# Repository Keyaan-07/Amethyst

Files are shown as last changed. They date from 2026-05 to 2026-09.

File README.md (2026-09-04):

# Amethyst
Amethyst is an 84-key keyboard with a small form factor. It comes with the RP2040 and i have used purple akko v3 switches to give it purple colour. This keyboard runs qmk firmware and can be found under firmware. The complete design file is amethyst.step.

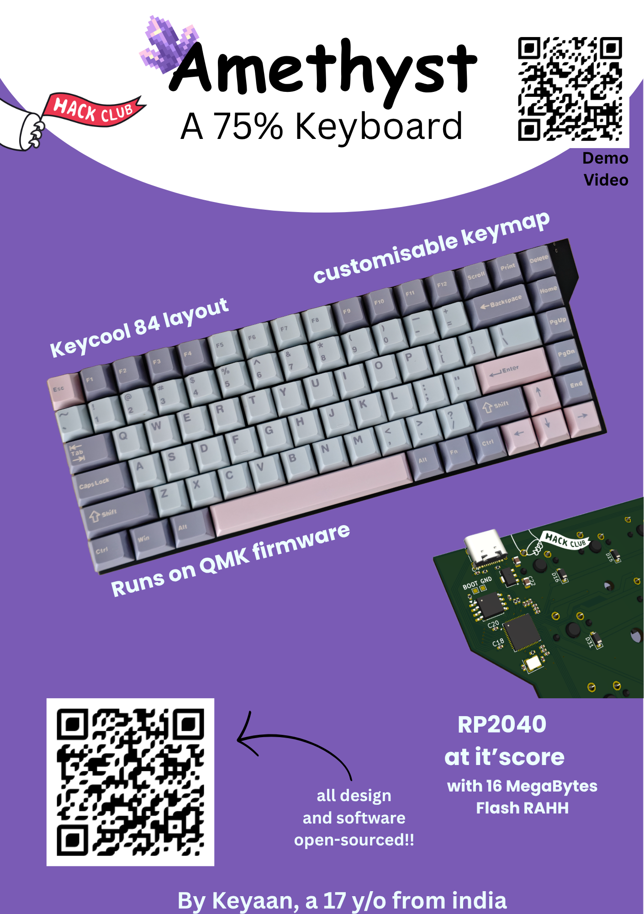
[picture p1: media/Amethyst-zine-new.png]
zine page

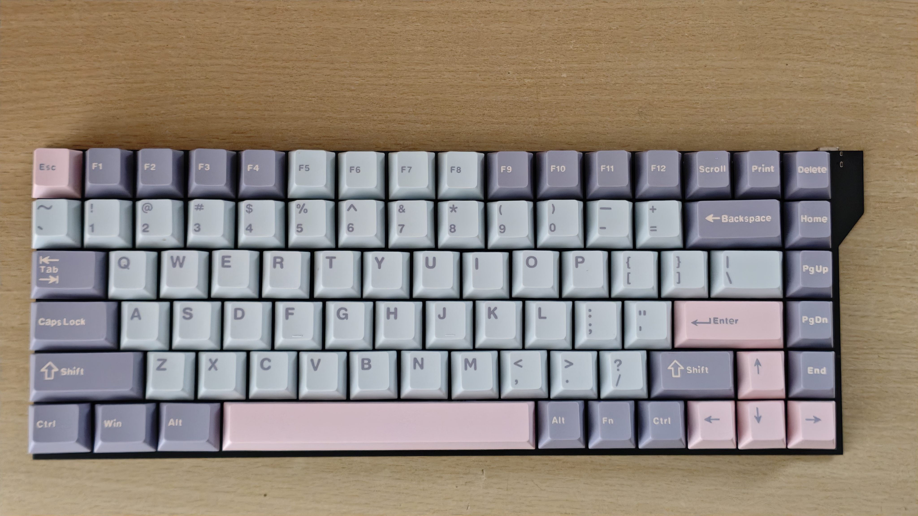
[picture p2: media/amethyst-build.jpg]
build

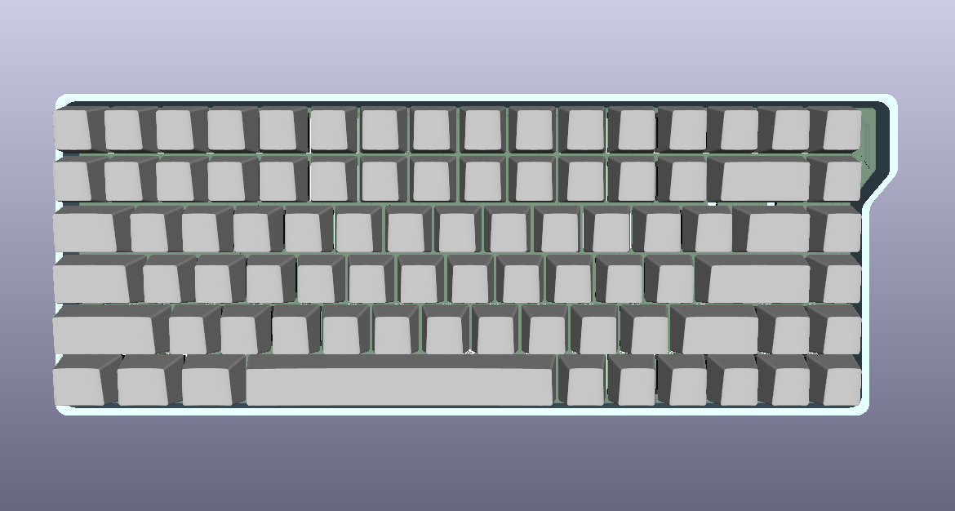
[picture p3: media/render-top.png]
render-top

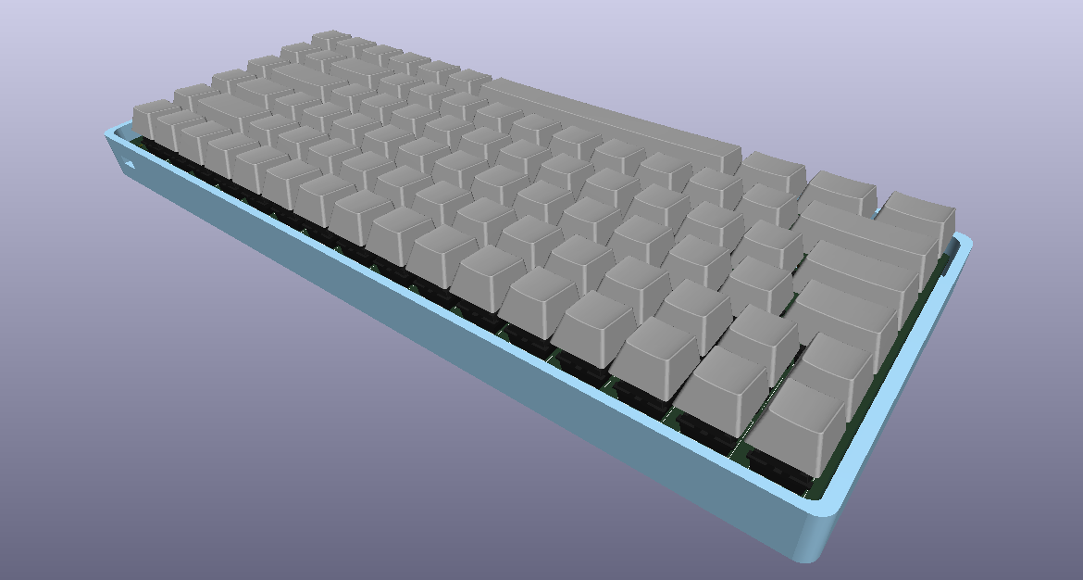
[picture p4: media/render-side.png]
render-side

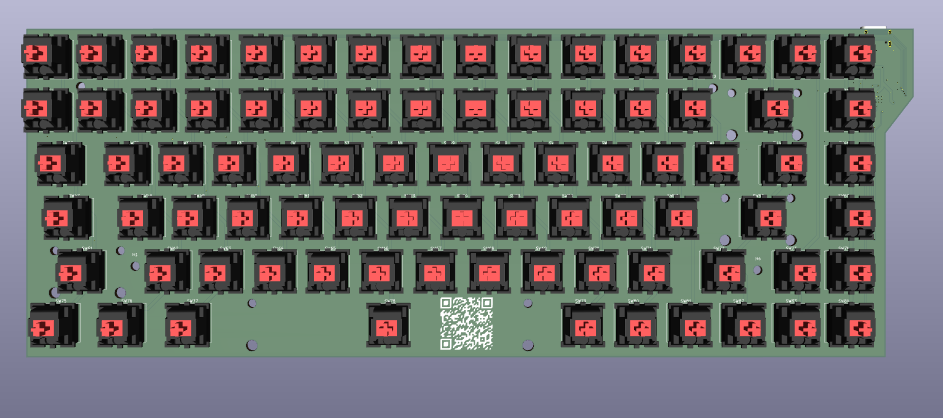
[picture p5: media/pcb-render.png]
pcb-render

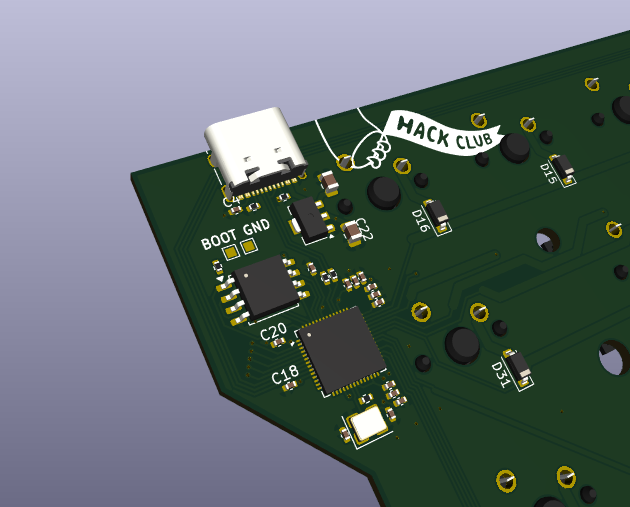
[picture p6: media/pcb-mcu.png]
pcb-mcu

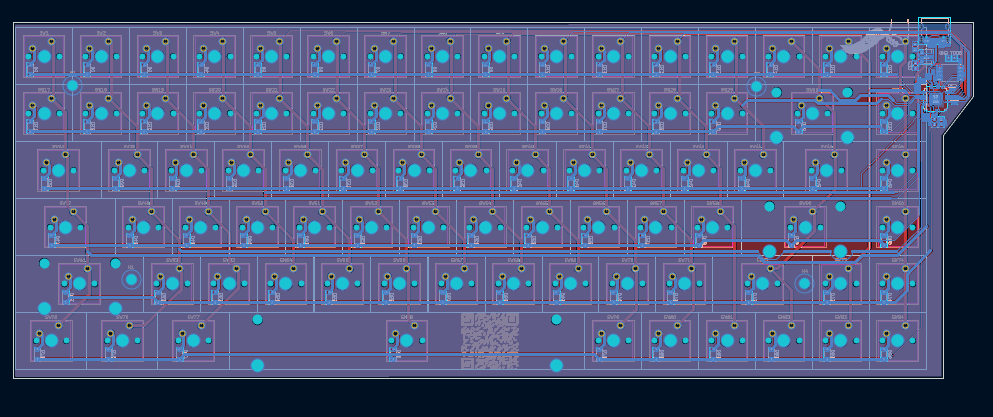
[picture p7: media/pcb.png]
pcb

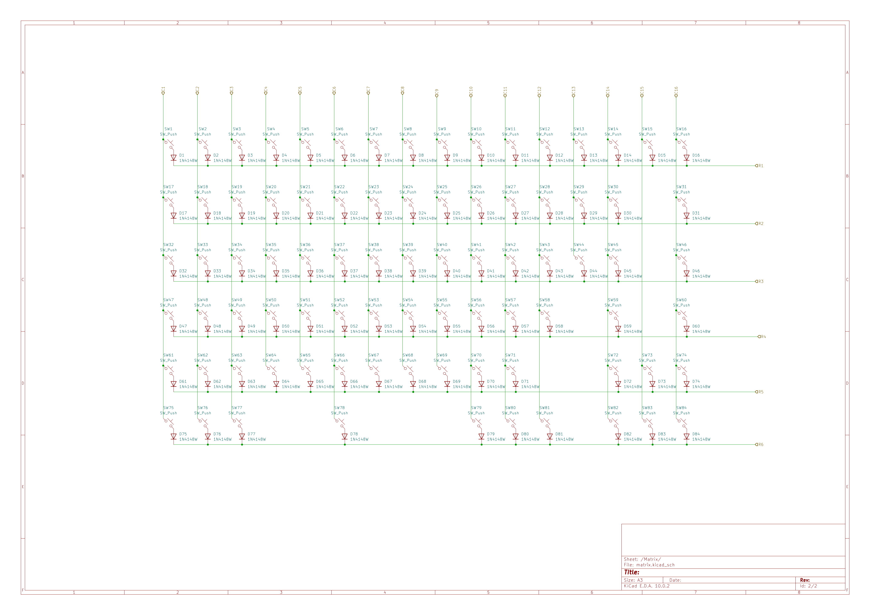
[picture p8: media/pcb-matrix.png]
matrix


# Soldering and setup
1. Order the PCB from the gerbers present in hardware/production. 
2. order the parts from the given links in bom.csv file
3. first solder the smd components on the back side and then proceed to the through hole keys. 
4. press the heated inserts in the case with the help of a soldering iron. 
5. screw in the case. 
6. fit the keycaps on the top. 
7. short the BOOT and GND pads with a screwdriver and plug in the usb cable.
8. go to the firmware folder and download the .uf2 file. 
9. drag and drop the .uf2 file to the "RPI-RP2" drive that just popped up.
10. Your keyboard is now ready!!

## Why I made this keyboard
 I am getting a new laptop this year and did not want to let go of the keymap of the old keyboard, thus I created amethyst. 

# BOM
|Designator |Function |Value |Footprint |Quantity|Price |Amount |Order|Link |
|---|---|---|---|---|---|---|-----|---|
|PCB |Main PCB | |119x312 |5 |8.934 |44.67  |Yes  |https://robu.in/product/online-pcb-manufacturing-service/ |
|Keycaps |Purple keycaps | | |1 |11.48 |11.48  |Yes  |https://curiositycaps.in/products/macarons-cherry-pbt-keycaps?_pos=368&_fid=c796727f4&_ss=c |
|Keys |Akko v3 lavender(pack of 45)  | | |2 |11.48 |22.96  |Yes  |https://stackskb.com/store/akko-v3-lavender-purple-pro-switch-pack-of-45/ |
|Stabilizers |Clear | | |1 |11.67 |11.67  |Yes  |https://stackskb.com/store/durock-clear-screw-in-stabilizers-v2/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 |
|Case |print legion | | |1 |0 |0 |Yes  |https://printlegion.hackclub.com/ |
|C1, C2 |Capacitor |15p |402 |2 |0.017 |0.034  |Yes  |https://robu.in/product/gjm1555c1h150gb01d-murata-electronics-50v-15pf-null-%c2%b12-0402-multilayer-ceramic-capacitors-mlcc-smd-smt-rohs/|
|C13, C22 |Capacitor |10u |805 |2 |0.05 |0.1 |No |https://www.lcsc.com/product-detail/C2932476.html |
|C14, C15, C16, C17, C18, C19, C20, C23, C24, C25 |Capacitor |100n |402 |10 |0.0074  |0.074  |No |https://www.lcsc.com/product-detail/C426067.html |
|C4, C5, C6 |Capacitor |1u |402 |3 |0.02 |0.06 |No |https://www.lcsc.com/product-detail/C1518208.html |
|D1, D10, D11, D12, D13, D14, D15, D16, D17, D18, D19, D2, D20, D21, D22, D23, D24, D25, D26, D27, D28, D29, D3, D30, D31, D32, D33, D34, D35, D36, D37, D38, D39, D4, D40, D41, D42, D43, D44, D45, D46, D47, D48, D49, D5, D50, D51, D52, D53, D54, D55, D56, D57, D58, D59, D6, D60, D61, D62, D63, D64, D65, D66, D67, D68, D69, D7, D70, D71, D72, D73, D74, D75, D76, D77, D78, D79, D8, D80, D81, D82, D83, D84, D9|Diodes |1N4148W |D_SOD-123 |90 |0.0073  |0.657  |Yes  |https://robu.in/product/1n4148w-sod-123-1206-diodereel-of-3000/ |
|J2 |USB-C |USB_C_Receptacle_USB2.0_16P|USB_C_Receptacle_XKB_U262-16XN-4BVC11|1 |0.06 |0.06 |No |https://www.lcsc.com/product-detail/C393939.html |
|R1, R2 |Resistors |5.1k |402 |2 |0.005 |0.01 |No |https://www.lcsc.com/product-detail/C278598.html |
|R3, R6 |Resistors |1k |402 |2 |0.02 |0.04 |No |https://www.lcsc.com/product-detail/C427241.html |
|R4, R5 |Resistors |27 |402 |2 |0.0039  |0.0078 |No |https://www.lcsc.com/product-detail/C278580.html |
|U1 |MCU |RP2040 |QFN-56-1EP_7x7mm_P0.4mm_EP3.2x3.2mm  |2 |0.89 |1.78 |Yes  |https://robu.in/product/raspberry-pi-rp2040/ |
|U2 |Flash |W25Q128JVS |SOIC-8_5.3x5.3mm_P1.27mm |1 |1.1 |1.1 |No |https://www.lcsc.com/product-detail/C2613930.html |
|U3 |Regulator |AMS1117-3.3 |SOT-89-3 |1 |0.1 |0.1 |No |https://www.lcsc.com/product-detail/C917152.html |
|Y1 |Crystal Oscillator |Crystal_GND24 |Crystal_SMD_3225-4Pin_3.2x2.5mm |1 |0.38 |0.38 |No |https://www.lcsc.com/product-detail/C20625731.html |
| | | | | |Shipping|0.51 | | |
| | | | | |Total |100.693| | |

# 3d Files link
All the 3d files can be found on onshape [here](https://cad.onshape.com/documents/0f11901139fd6ce9006e5c5f/w/93aac7747a7c2381c6948375/e/141b0f824d8e79d984ecb6aa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)

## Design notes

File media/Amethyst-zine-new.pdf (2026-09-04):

## A 75% Keyboard

# Amethyst

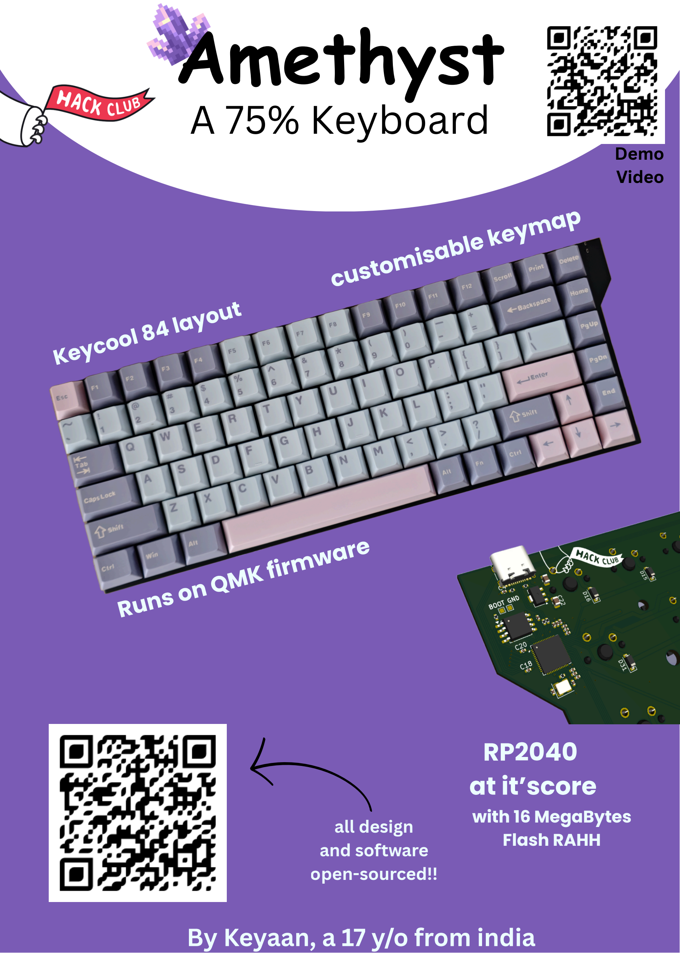
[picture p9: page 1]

By Keyaan, a 17 y/o from india all design
and software
open-sourced!!

Runs on QMK firmware

customisable keymap

RP2040
at it’score
with 16 MegaBytes
Flash RAHH

Keycool 84 layout

Demo
Video

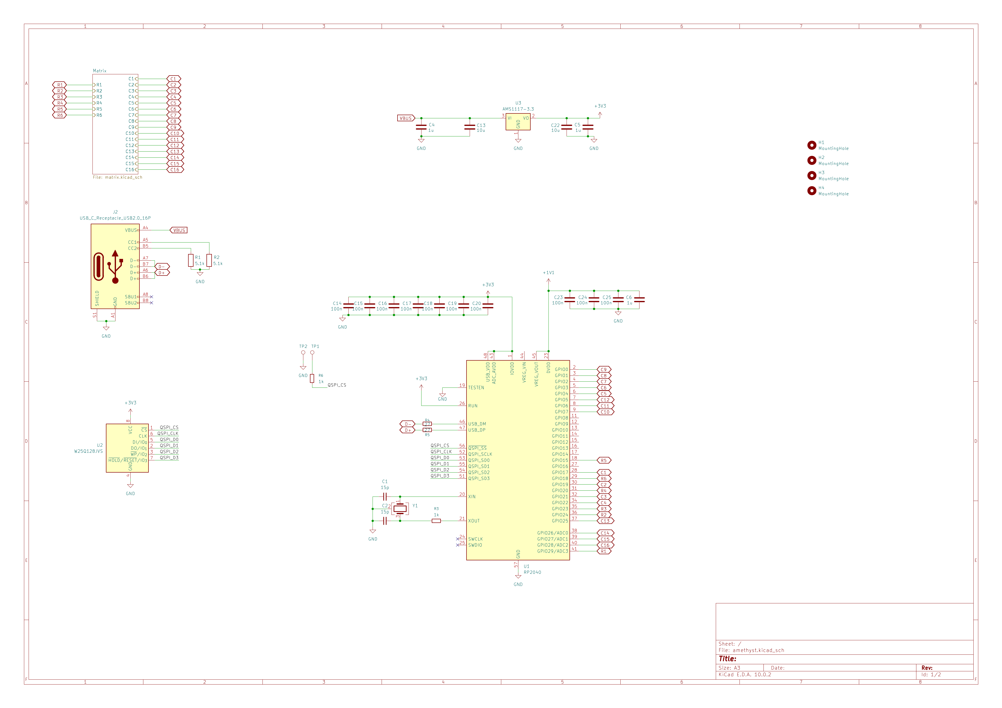
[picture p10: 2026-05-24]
media/schematic-mcu.png

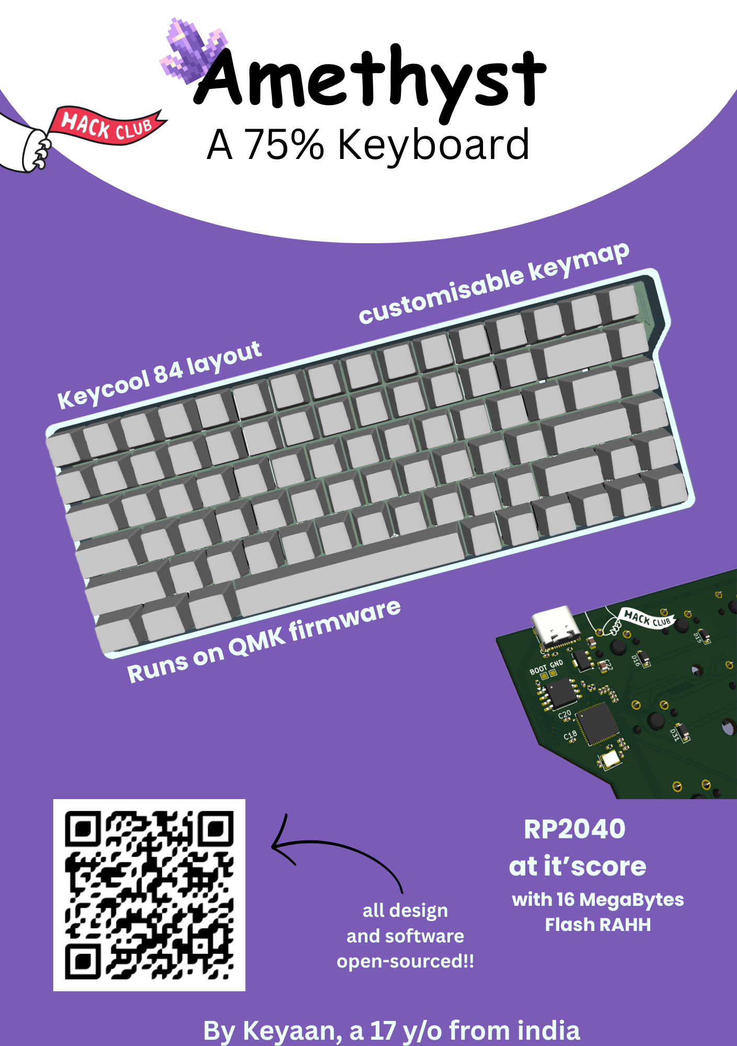
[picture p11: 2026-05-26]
media/Amethyst-zine.png

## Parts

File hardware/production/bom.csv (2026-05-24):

Designator | Footprint | Quantity | Value | LCSC Part #
C1, C2 | 0402 | 2 | 15p
C13, C22 | 0805 | 2 | 10u
C14, C15, C16, C17, C18, C19, C20, C23, C24, C25 | 0402 | 10 | 100n
C4, C5, C6 | 0402 | 3 | 1u
D1, D10, D11, D12, D13, D14, D15, D16, D17, D18, D19, D2, D20, D21, D22, D23, D24, D25, D26, D27, D28, D29, D3, D30, D31, D32, D33, D34, D35, D36, D37, D38, D39, D4, D40, D41, D42, D43, D44, D45, D46, D47, D48, D49, D5, D50, D51, D52, D53, D54, D55, D56, D57, D58, D59, D6, D60, D61, D62, D63, D64, D65, D66, D67, D68, D69, D7, D70, D71, D72, D73, D74, D75, D76, D77, D78, D79, D8, D80, D81, D82, D83, D84, D9 | D_SOD-123 | 84 | 1N4148W
J2 | USB_C_Receptacle_XKB_U262-16XN-4BVC11 | 1 | USB_C_Receptacle_USB2.0_16P
R1, R2 | 0402 | 2 | 5.1k
R3, R6 | 0402 | 2 | 1k
R4, R5 | 0402 | 2 | 27
SW1, SW10, SW11, SW12, SW13, SW14, SW15, SW16, SW17, SW18, SW19, SW2, SW20, SW21, SW22, SW23, SW24, SW25, SW26, SW27, SW28, SW29, SW3, SW31, SW33, SW34, SW35, SW36, SW37, SW38, SW39, SW4, SW40, SW41, SW42, SW43, SW44, SW46, SW48, SW49, SW5, SW50, SW51, SW52, SW53, SW54, SW55, SW56, SW57, SW58, SW6, SW60, SW62, SW63, SW64, SW65, SW66, SW67, SW68, SW69, SW7, SW70, SW71, SW73, SW74, SW79, SW8, SW80, SW81, SW82, SW83, SW84, SW9 | SW_Cherry_MX_1.00u_PCB | 73 | SW_Push
SW30 | SW_Cherry_MX_2.00u_PCB | 1 | SW_Push
SW32, SW45 | SW_Cherry_MX_1.50u_PCB | 2 | SW_Push
SW47, SW72 | SW_Cherry_MX_1.75u_PCB | 2 | SW_Push
SW59, SW61 | SW_Cherry_MX_2.25u_PCB | 2 | SW_Push
SW75, SW76, SW77 | SW_Cherry_MX_1.25u_PCB | 3 | SW_Push
SW78 | SW_Cherry_MX_6.25u_PCB | 1 | SW_Push
TP1, TP2 | TestPoint_Pad_1.0x1.0mm | 2 | TestPoint
U1 | QFN-56-1EP_7x7mm_P0.4mm_EP3.2x3.2mm | 1 | RP2040
U2 | SOIC-8_5.3x5.3mm_P1.27mm | 1 | W25Q128JVS
U3 | SOT-89-3 | 1 | AMS1117-3.3
Y1 | Crystal_SMD_3225-4Pin_3.2x2.5mm | 1 | Crystal_GND24

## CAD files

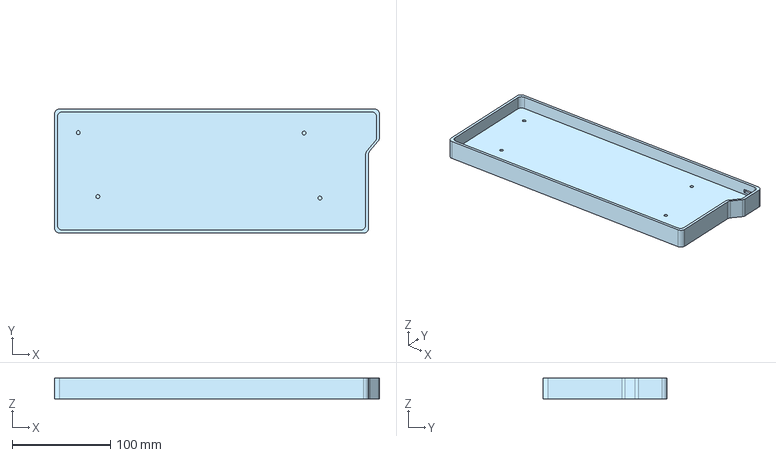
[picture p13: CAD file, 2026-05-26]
threedimensions/Amethyst_case.step
330.0 x 126.0 x 21.0 mm

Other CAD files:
threedimensions/amethyst_case.stl

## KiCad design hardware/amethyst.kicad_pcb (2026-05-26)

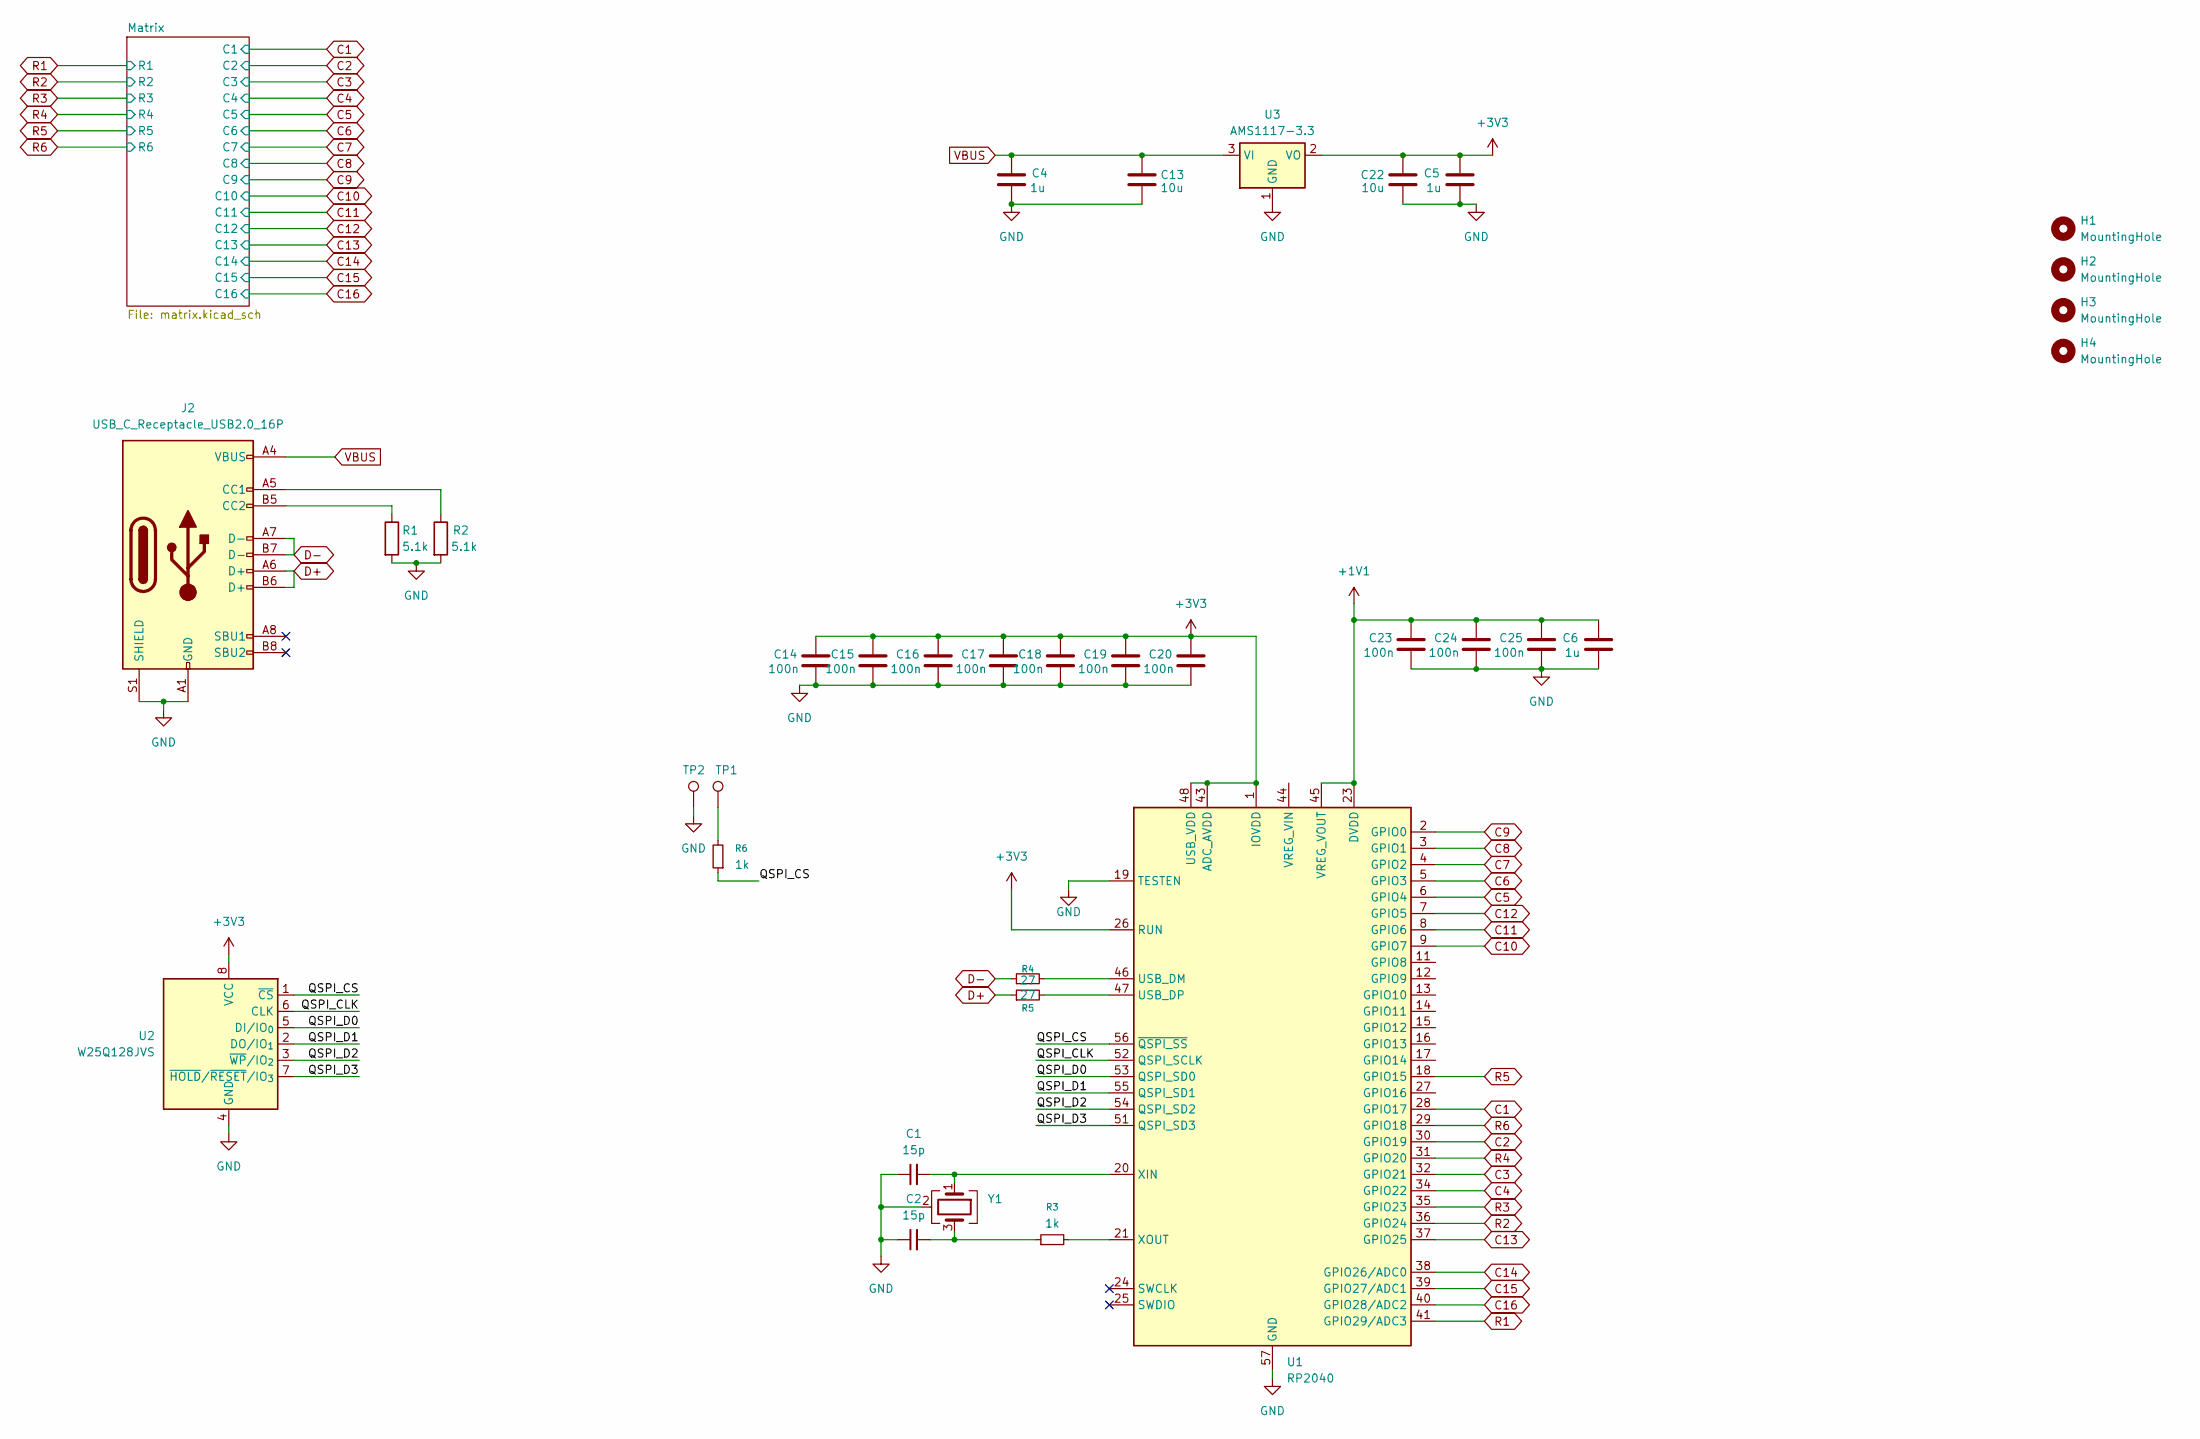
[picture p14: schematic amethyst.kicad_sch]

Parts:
C1, C2: 15p; C_0402_1005Metric
C4, C5, C6: 1u; C_0402_1005Metric
C13, C22: 10u; C_0805_2012Metric
C14, C15, C16, C17, C18, C19, C20, C23, C24, C25: 100n; C_0402_1005Metric
H1, H2, H3, H4: MountingHole; MountingHole_3.2mm_M3
J2: USB_C_Receptacle_USB2.0_16P; USB_C_Receptacle_XKB_U262-16XN-4BVC11
R1, R2: 5.1k; R_0402_1005Metric
R3, R6: 1k; R_0402_1005Metric
R4, R5: 27; R_0402_1005Metric
TP1, TP2: TestPoint; TestPoint_Pad_1.0x1.0mm
U1: RP2040; QFN-56-1EP_7x7mm_P0.4mm_EP3.2x3.2mm
U2: W25Q128JVS; SOIC-8_5.3x5.3mm_P1.27mm
U3: AMS1117-3.3; SOT-89-3
Y1: Crystal_GND24; Crystal_SMD_3225-4Pin_3.2x2.5mm

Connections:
+1V1: C6.2, C23.2, C24.2, C25.2, U1.23 (DVDD), U1.45 (VREG_VOUT), U1.50 (DVDD)
+3V3: C5.2, C14.2, C15.2, C16.2, C17.2, C18.2, C19.2, C20.2, C22.1, U1.1 (IOVDD), U1.10 (IOVDD), U1.22 (IOVDD), U1.26 (RUN), U1.33 (IOVDD), U1.42 (IOVDD), U1.43 (ADC_AVDD), U1.48 (USB_VDD), U1.49 (IOVDD), U2.8 (VCC), U3.2 (VO)
/QSPI_CLK: U1.52 (QSPI_SCLK), U2.6 (CLK)
/QSPI_CS: R6.1, U1.56 (~QSPI_SS), U2.1 (~CS)
/QSPI_D0: U1.53 (QSPI_SD0), U2.5 (DI/IO_{0})
/QSPI_D1: U1.55 (QSPI_SD1), U2.2 (DO/IO_{1})
/QSPI_D2: U1.54 (QSPI_SD2), U2.3 (~WP/IO_{2})
/QSPI_D3: U1.51 (QSPI_SD3), U2.7 (~HOLD/~RESET/IO_{3})
C1: U1.28 (GPIO17); also elsewhere on the board
C2: U1.30 (GPIO19); also elsewhere on the board
C3: U1.32 (GPIO21); also elsewhere on the board
C4: U1.34 (GPIO22); also elsewhere on the board
C5: U1.6 (GPIO4); also elsewhere on the board
C6: U1.5 (GPIO3); also elsewhere on the board
C7: U1.4 (GPIO2); also elsewhere on the board
C8: U1.3 (GPIO1); also elsewhere on the board
C9: U1.2 (GPIO0); also elsewhere on the board
C10: U1.9 (GPIO7); also elsewhere on the board
C11: U1.8 (GPIO6); also elsewhere on the board
C12: U1.7 (GPIO5); also elsewhere on the board
C13: U1.37 (GPIO25); also elsewhere on the board
C14: U1.38 (GPIO26/ADC0); also elsewhere on the board
C15: U1.39 (GPIO27/ADC1); also elsewhere on the board
C16: U1.40 (GPIO28/ADC2); also elsewhere on the board
D+: J2.A6 (D+), J2.B6 (D+), R5.1
D-: J2.A7 (D-), J2.B7 (D-), R4.1
GND: C1.1, C2.1, C4.1, C5.1, C6.1, C13.2, C14.1, C15.1, C16.1, C17.1, C18.1, C19.1, C20.1, C22.2, C23.1, C24.1, C25.1, J2.A1 (GND), J2.A12 (GND), J2.B1 (GND), J2.B12 (GND), J2.S1 (SHIELD), R1.2, R2.2, TP2.1 (1_1), U1.19 (TESTEN), U1.57 (GND), U2.4 (GND), U3.1 (GND), Y1.2 (G), Y1.4 (G)
unnamed: C2.2, R3.1, Y1.3
unnamed: J2.A5 (CC1), R2.1
unnamed: J2.B5 (CC2), R1.1
unnamed: R6.2, TP1.1 (1_1)
unnamed: R4.2, U1.46 (USB_DM)
unnamed: R5.2, U1.47 (USB_DP)
unnamed: C1.2, U1.20 (XIN), Y1.1
unnamed: R3.2, U1.21 (XOUT)
R1: U1.41 (GPIO29/ADC3); also elsewhere on the board
R2: U1.36 (GPIO24); also elsewhere on the board
R3: U1.35 (GPIO23); also elsewhere on the board
R4: U1.31 (GPIO20); also elsewhere on the board
R5: U1.18 (GPIO15); also elsewhere on the board
R6: U1.29 (GPIO18); also elsewhere on the board
VBUS: C4.2, C13.1, J2.A4 (VBUS), J2.A9 (VBUS), J2.B4 (VBUS), J2.B9 (VBUS), U3.3 (VI)

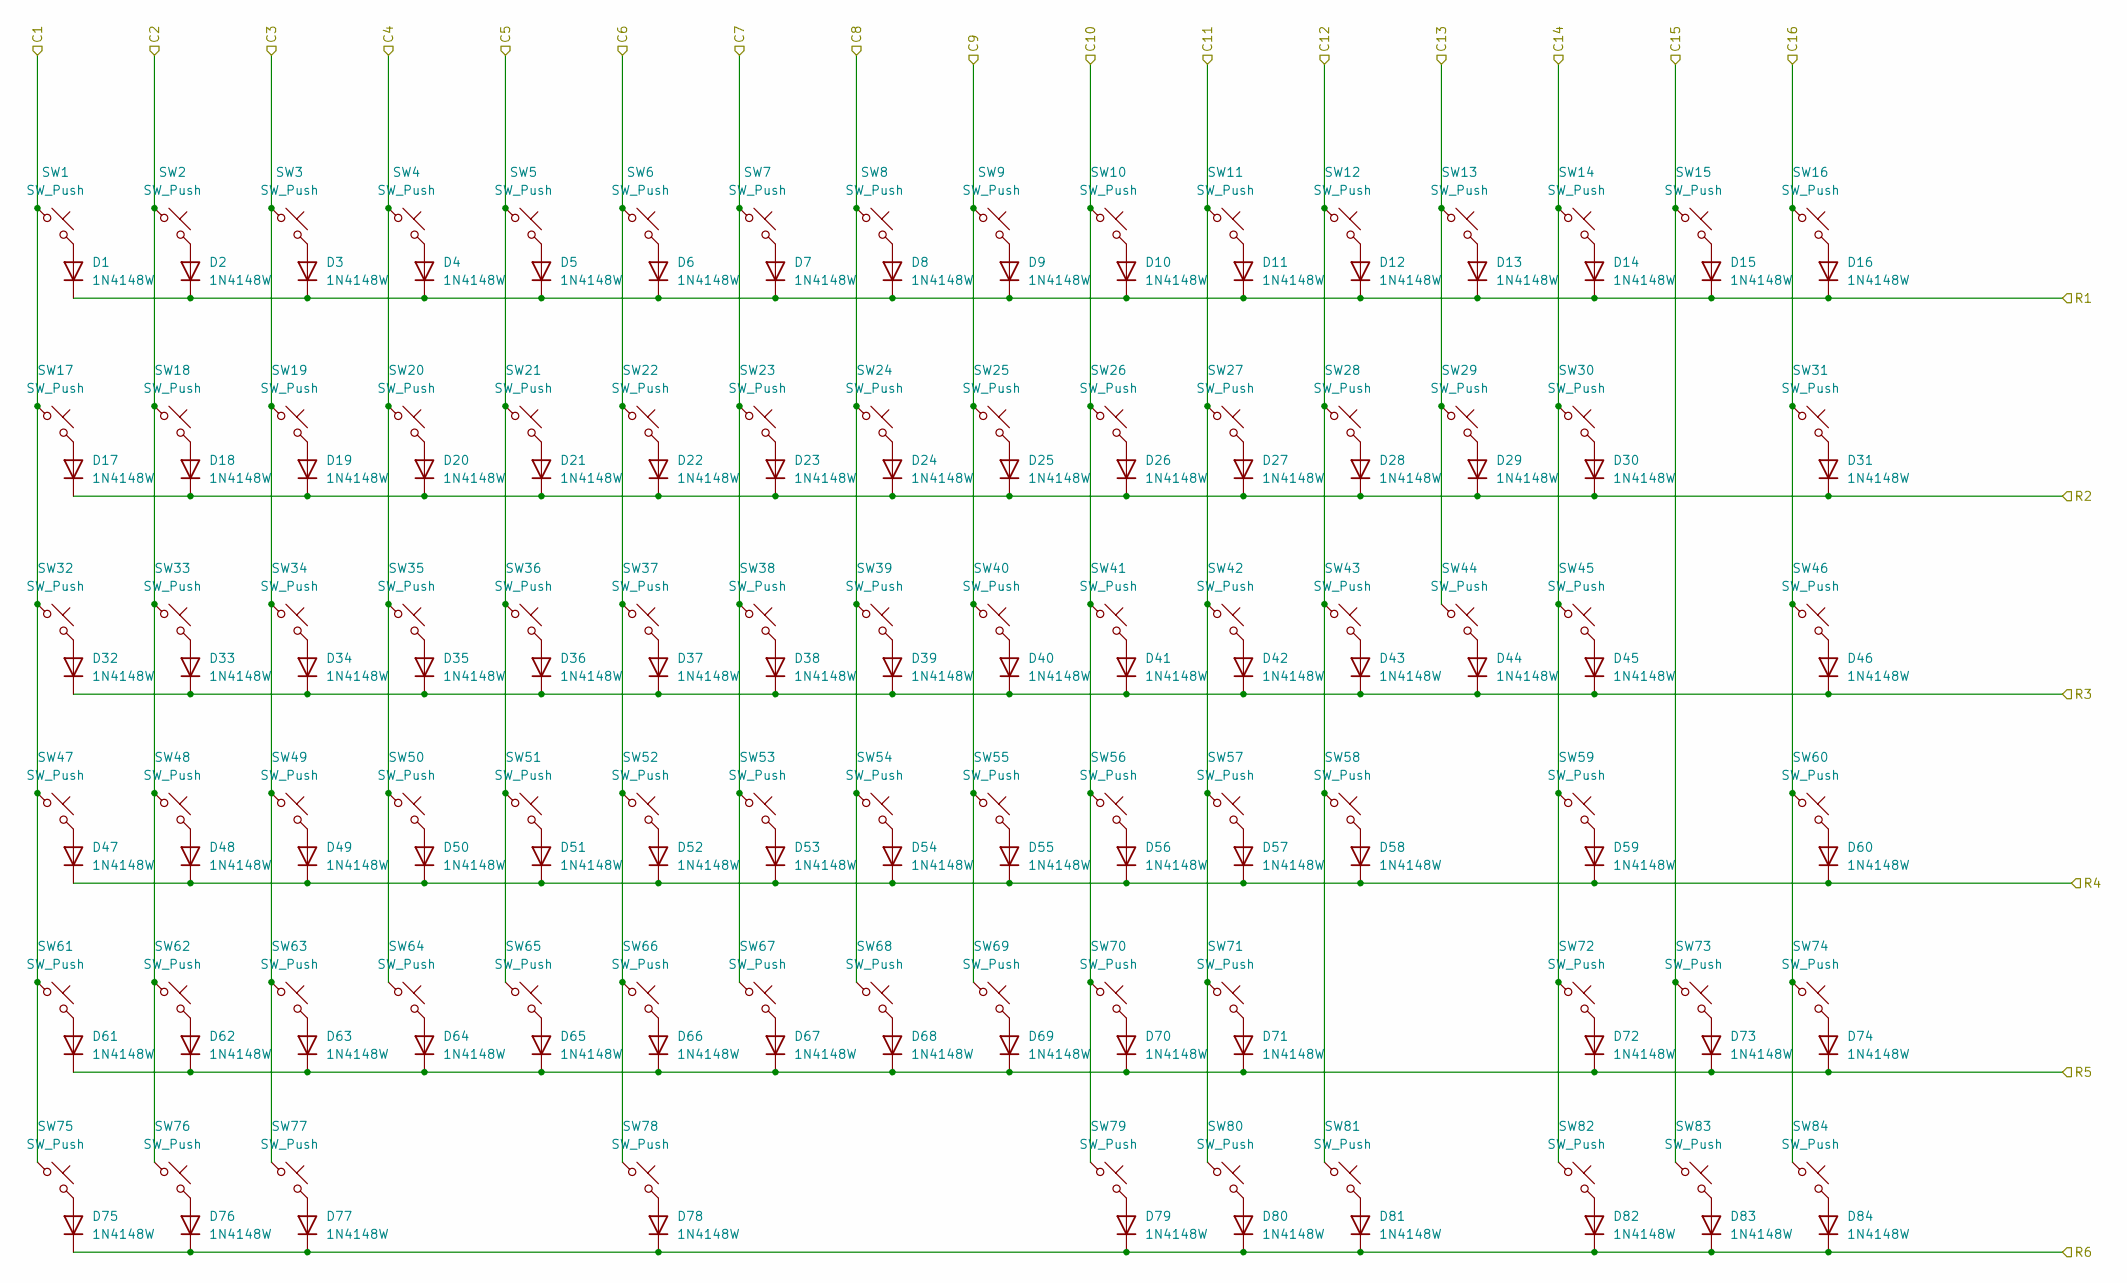
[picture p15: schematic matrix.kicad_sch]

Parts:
D1, D2, D3, D4, D5, D6, D7, D8, D9, D10, D11, D12, D13, D14, D15, D16, D17, D18, D19, D20, D21, D22, D23, D24, D25, D26, D27, D28, D29, D30, D31, D32, D33, D34, D35, D36, D37, D38, D39, D40, D41, D42, D43, D44, D45, D46, D47, D48, D49, D50, D51, D52, D53, D54, D55, D56, D57, D58, D59, D60, D61, D62, D63, D64, D65, D66, D67, D68, D69, D70, D71, D72, D73, D74, D75, D76, D77, D78, D79, D80, D81, D82, D83, D84: 1N4148W; D_SOD-123
SW1, SW2, SW3, SW4, SW5, SW6, SW7, SW8, SW9, SW10, SW11, SW12, SW13, SW14, SW15, SW16, SW17, SW18, SW19, SW20, SW21, SW22, SW23, SW24, SW25, SW26, SW27, SW28, SW29, SW31, SW33, SW34, SW35, SW36, SW37, SW38, SW39, SW40, SW41, SW42, SW43, SW44, SW46, SW48, SW49, SW50, SW51, SW52, SW53, SW54, SW55, SW56, SW57, SW58, SW60, SW62, SW63, SW64, SW65, SW66, SW67, SW68, SW69, SW70, SW71, SW73, SW74, SW79, SW80, SW81, SW82, SW83, SW84: SW_Push; SW_Cherry_MX_1.00u_PCB
SW30: SW_Push; SW_Cherry_MX_2.00u_PCB
SW32, SW45: SW_Push; SW_Cherry_MX_1.50u_PCB
SW47, SW72: SW_Push; SW_Cherry_MX_1.75u_PCB
SW59, SW61: SW_Push; SW_Cherry_MX_2.25u_PCB
SW75, SW76, SW77: SW_Push; SW_Cherry_MX_1.25u_PCB
SW78: SW_Push; SW_Cherry_MX_6.25u_PCB

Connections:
C1: SW1.1, SW17.1, SW32.1, SW47.1, SW61.1, SW75.1; also elsewhere on the board
C2: SW2.1, SW18.1, SW33.1, SW48.1, SW62.1, SW76.1; also elsewhere on the board
C3: SW3.1, SW19.1, SW34.1, SW49.1, SW63.1, SW77.1; also elsewhere on the board
C4: SW4.1, SW20.1, SW35.1, SW50.1, SW64.1; also elsewhere on the board
C5: SW5.1, SW21.1, SW36.1, SW51.1, SW65.1; also elsewhere on the board
C6: SW6.1, SW22.1, SW37.1, SW52.1, SW66.1, SW78.1; also elsewhere on the board
C7: SW7.1, SW23.1, SW38.1, SW53.1, SW67.1; also elsewhere on the board
C8: SW8.1, SW24.1, SW39.1, SW54.1, SW68.1; also elsewhere on the board
C9: SW9.1, SW25.1, SW40.1, SW55.1, SW69.1; also elsewhere on the board
C10: SW10.1, SW26.1, SW41.1, SW56.1, SW70.1, SW79.1; also elsewhere on the board
C11: SW11.1, SW27.1, SW42.1, SW57.1, SW71.1, SW80.1; also elsewhere on the board
C12: SW12.1, SW28.1, SW43.1, SW58.1, SW81.1; also elsewhere on the board
C13: SW13.1, SW29.1, SW44.1; also elsewhere on the board
C14: SW14.1, SW30.1, SW45.1, SW59.1, SW72.1, SW82.1; also elsewhere on the board
C15: SW15.1, SW73.1, SW83.1; also elsewhere on the board
C16: SW16.1, SW31.1, SW46.1, SW60.1, SW74.1, SW84.1; also elsewhere on the board
unnamed: D1.2 (A), SW1.2
unnamed: D2.2 (A), SW2.2
unnamed: D3.2 (A), SW3.2
unnamed: D4.2 (A), SW4.2
unnamed: D5.2 (A), SW5.2
unnamed: D6.2 (A), SW6.2
unnamed: D7.2 (A), SW7.2
unnamed: D8.2 (A), SW8.2
unnamed: D9.2 (A), SW9.2
unnamed: D10.2 (A), SW10.2
unnamed: D11.2 (A), SW11.2
unnamed: D12.2 (A), SW12.2
unnamed: D13.2 (A), SW13.2
unnamed: D14.2 (A), SW14.2
unnamed: D15.2 (A), SW15.2
unnamed: D16.2 (A), SW16.2
unnamed: D17.2 (A), SW17.2
unnamed: D18.2 (A), SW18.2
unnamed: D19.2 (A), SW19.2
unnamed: D20.2 (A), SW20.2
unnamed: D21.2 (A), SW21.2
unnamed: D22.2 (A), SW22.2
unnamed: D23.2 (A), SW23.2
unnamed: D24.2 (A), SW24.2
unnamed: D25.2 (A), SW25.2
unnamed: D26.2 (A), SW26.2
unnamed: D27.2 (A), SW27.2
unnamed: D28.2 (A), SW28.2
unnamed: D29.2 (A), SW29.2
unnamed: D30.2 (A), SW30.2
unnamed: D31.2 (A), SW31.2
unnamed: D32.2 (A), SW32.2
unnamed: D33.2 (A), SW33.2
unnamed: D34.2 (A), SW34.2
unnamed: D35.2 (A), SW35.2
unnamed: D36.2 (A), SW36.2
unnamed: D37.2 (A), SW37.2
unnamed: D38.2 (A), SW38.2
unnamed: D39.2 (A), SW39.2
unnamed: D40.2 (A), SW40.2
unnamed: D41.2 (A), SW41.2
unnamed: D42.2 (A), SW42.2
unnamed: D43.2 (A), SW43.2
unnamed: D44.2 (A), SW44.2
unnamed: D45.2 (A), SW45.2
unnamed: D46.2 (A), SW46.2
unnamed: D47.2 (A), SW47.2
unnamed: D48.2 (A), SW48.2
unnamed: D49.2 (A), SW49.2
unnamed: D50.2 (A), SW50.2
unnamed: D51.2 (A), SW51.2
unnamed: D52.2 (A), SW52.2
unnamed: D53.2 (A), SW53.2
unnamed: D54.2 (A), SW54.2
unnamed: D55.2 (A), SW55.2
unnamed: D56.2 (A), SW56.2
unnamed: D57.2 (A), SW57.2
unnamed: D58.2 (A), SW58.2
unnamed: D59.2 (A), SW59.2
unnamed: D60.2 (A), SW60.2
unnamed: D61.2 (A), SW61.2
unnamed: D62.2 (A), SW62.2
unnamed: D63.2 (A), SW63.2
unnamed: D64.2 (A), SW64.2
unnamed: D65.2 (A), SW65.2
unnamed: D66.2 (A), SW66.2
unnamed: D67.2 (A), SW67.2
unnamed: D68.2 (A), SW68.2
unnamed: D69.2 (A), SW69.2
unnamed: D70.2 (A), SW70.2
unnamed: D71.2 (A), SW71.2
unnamed: D72.2 (A), SW72.2
unnamed: D73.2 (A), SW73.2
unnamed: D74.2 (A), SW74.2
unnamed: D75.2 (A), SW75.2
unnamed: D76.2 (A), SW76.2
unnamed: D77.2 (A), SW77.2
unnamed: D78.2 (A), SW78.2
unnamed: D79.2 (A), SW79.2
unnamed: D80.2 (A), SW80.2
unnamed: D81.2 (A), SW81.2
unnamed: D82.2 (A), SW82.2
unnamed: D83.2 (A), SW83.2
unnamed: D84.2 (A), SW84.2
R1: D1.1 (K), D2.1 (K), D3.1 (K), D4.1 (K), D5.1 (K), D6.1 (K), D7.1 (K), D8.1 (K), D9.1 (K), D10.1 (K), D11.1 (K), D12.1 (K), D13.1 (K), D14.1 (K), D15.1 (K), D16.1 (K); also elsewhere on the board
R2: D17.1 (K), D18.1 (K), D19.1 (K), D20.1 (K), D21.1 (K), D22.1 (K), D23.1 (K), D24.1 (K), D25.1 (K), D26.1 (K), D27.1 (K), D28.1 (K), D29.1 (K), D30.1 (K), D31.1 (K); also elsewhere on the board
R3: D32.1 (K), D33.1 (K), D34.1 (K), D35.1 (K), D36.1 (K), D37.1 (K), D38.1 (K), D39.1 (K), D40.1 (K), D41.1 (K), D42.1 (K), D43.1 (K), D44.1 (K), D45.1 (K), D46.1 (K); also elsewhere on the board
R4: D47.1 (K), D48.1 (K), D49.1 (K), D50.1 (K), D51.1 (K), D52.1 (K), D53.1 (K), D54.1 (K), D55.1 (K), D56.1 (K), D57.1 (K), D58.1 (K), D59.1 (K), D60.1 (K); also elsewhere on the board
R5: D61.1 (K), D62.1 (K), D63.1 (K), D64.1 (K), D65.1 (K), D66.1 (K), D67.1 (K), D68.1 (K), D69.1 (K), D70.1 (K), D71.1 (K), D72.1 (K), D73.1 (K), D74.1 (K); also elsewhere on the board
R6: D75.1 (K), D76.1 (K), D77.1 (K), D78.1 (K), D79.1 (K), D80.1 (K), D81.1 (K), D82.1 (K), D83.1 (K), D84.1 (K); also elsewhere on the board

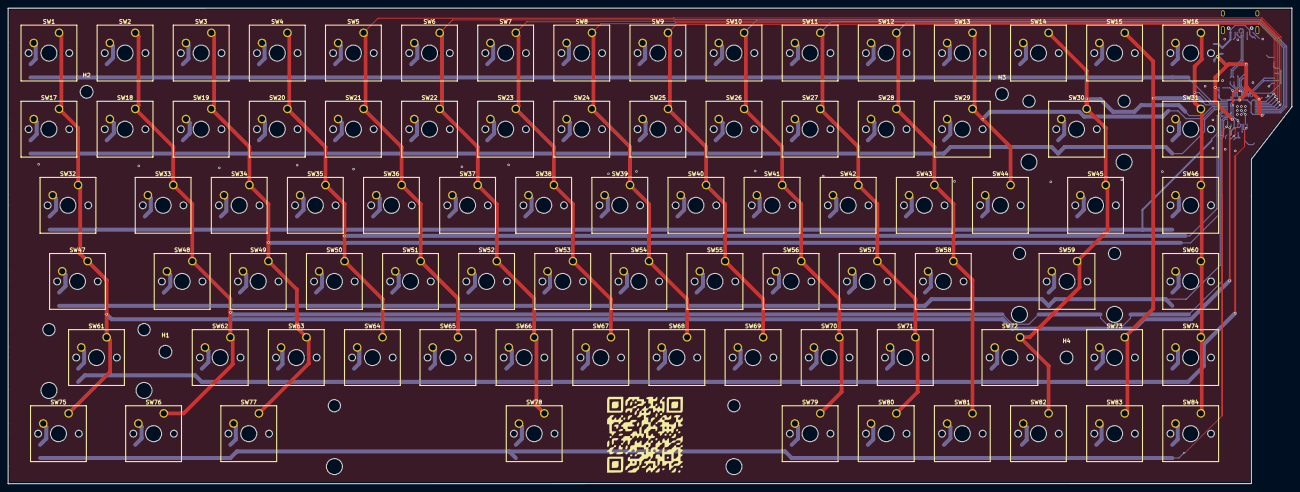
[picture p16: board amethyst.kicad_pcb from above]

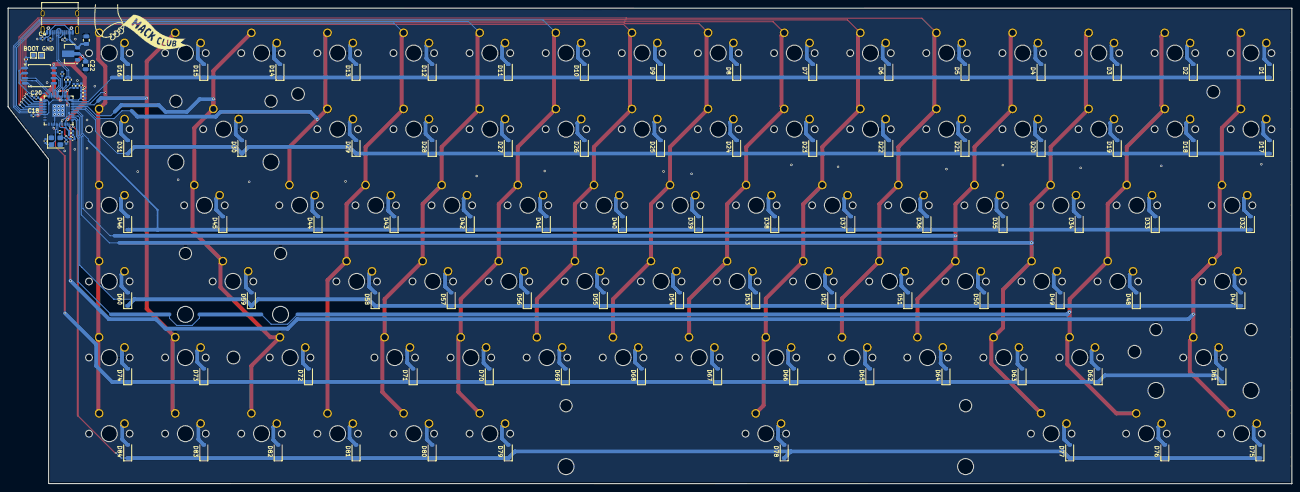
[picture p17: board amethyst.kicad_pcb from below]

Board: 2 copper layers, 321.3 x 119.0 mm, 202 parts (114 on the bottom side), 126 nets.

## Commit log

2026-04-29 Matrix Complete
    [amethyst.kicad_pcb, amethyst.kicad_sch, matrix.kicad_sch]
2026-04-29 Layout done
    [amethyst.kicad_pcb, amethyst.kicad_sch, matrix.kicad_sch]
2026-04-30 PCB Routing
    [amethyst.kicad_pcb, amethyst.kicad_sch, matrix.kicad_sch]
2026-05-01 Power circuitry and nrf52840 circuitry
    [amethyst.kicad_pcb, amethyst.kicad_sch]
2026-05-03 Matrix Routing and antenna placement
    [amethyst.kicad_pcb, amethyst.kicad_sch]
2026-05-03 matrix routing
    [amethyst.kicad_pcb, amethyst.kicad_sch]
2026-05-04 Routing complete
    [amethyst.kicad_pcb, amethyst.kicad_sch]
2026-05-05 Antenna matching done
    [amethyst.kicad_pcb]
2026-05-08 Prod files
    [amethyst.kicad_pcb, amethyst.kicad_sch, bom.csv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]
2026-05-16 new MCU
    [amethyst.kicad_pcb, amethyst.kicad_sch, matrix.kicad_sch]
2026-05-17 PCB redone
    [amethyst.kicad_pcb, amethyst.kicad_sch, bom.csv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]
2026-05-23 all the three dimensional files
    [Amethyst_case.step]
2026-05-24 Schematic Image
2026-05-24 PCB 3d model
2026-05-24 Latest Production files
    [amethyst.kicad_pcb, amethyst.kicad_sch, bom.csv]
2026-05-24 updated BOM
    [bom.csv]
2026-05-24 updated BOM in the readme
2026-05-26 new PCB design file
2026-05-26 render for images
    [amethyst.kicad_pcb]
2026-05-26 add description for key caps
    [bom.csv]
2026-05-26 Updated hole height in the case
    [Amethyst_case.step]
2026-06-03 updated files for 3d models
    [amethyst_case.stl]
2026-06-03 pcb completed.
    [amethyst.kicad_pcb]
